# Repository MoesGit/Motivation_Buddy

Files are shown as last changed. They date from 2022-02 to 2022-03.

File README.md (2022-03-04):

# Motivation_Buddy
A little IoT Device for Motivation and personal Messages. </br>
</br>
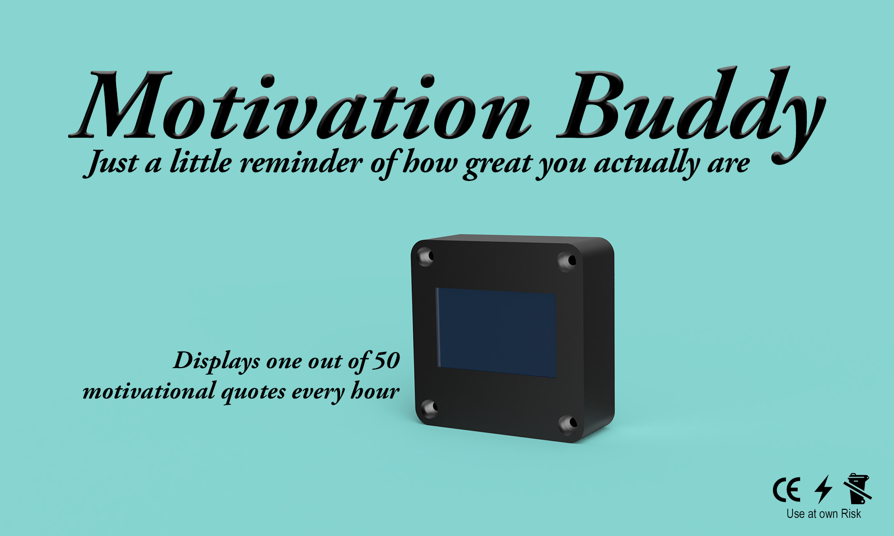
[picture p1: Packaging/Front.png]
Graph1

(just for fun and definitely has no CE certificate and not China Exportet since it is made at home (Please don't sue me. The Logo is just for fun :) ))

## What is it?
The Motivation Buddy is a little device, that can display a Motivation Quoate every hour or so. You can also hook it up to your WIFI to send messages and pre-set images to the screen. I designed this project as a gift. 

If you do not want to hook it up to Wifi it just displays a random quote which changes from time to time (i think - haven't tested it)

## Required Hardware:
- [ESP8266 D1 Mini](https://www.az-delivery.de/it/products/d1-mini-pro)
- [0.96 Inch Oled I2C Display](https://www.az-delivery.de/it/products/0-96zolldisplay?_pos=1&_sid=81bd66783&_ss=r)
- 4x [M2x6](https://www.amazon.de/Schrauben-Edelstahl-Sechskopf-Unterlegscheiben-Aufbewahrung/dp/B085LJYF3G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)
- Brass Inserts 4x [M2x4x3.5](https://www.amazon.de/VIGRUE-Gewindeeinsatz-Einpressmutter-Gewindebuchsen-Kunststoffteiledurch/dp/B08DHYD73Q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) 
- 4x 4cm Wire (2 [Arduino Jumper](https://www.amazon.de/Female-Female-Male-Female-Male-Male-Steckbr%C3%BCcken-Drahtbr%C3%BCcken-bunt/dp/B01EV70C78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) cables cut in halfe work too)

## Additionally: 
- [Arduino IDE](https://www.arduino.cc/en/software) addapted for [ESP8266](https://chewett.co.uk/blog/937/configuring-wemos-d1-mini-pro-esp8266-arduino-ide/)
- Solderin Iron 
- Solder
- 3D Printer 

## How to [Hardware]:

### 1) 3D Printing  
3D print the case and cover from the latest version in [3dModells](./3dModells/). I used the [colorFabb Steelfill PLA Filament](https://colorfabb.com/de/steelfill) for a High-Quality feeling and a bit of extra weight. 

Printer: 
- Ender 3 Pro
    
Print Settings (Cura 4.12.1): 
- Steal Nozzel 0.6mm
- Bed Tmp: 60°
- Nozzle: 215°
- Speed: 50mm/s
- Support: Tree, touching build plate
 - Retraction: 5mm

### 2) Soldering  
Solder the display to the ESP8266 D1 mini as shown below: 

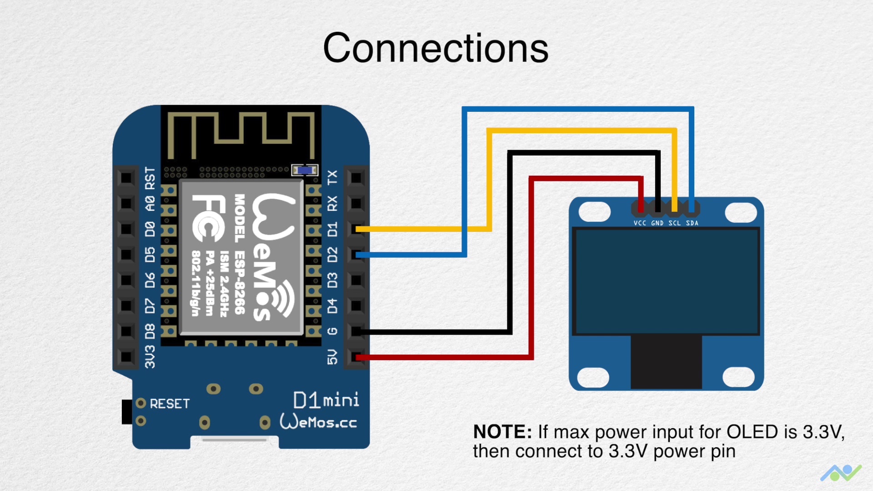
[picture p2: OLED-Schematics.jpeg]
solder_help

image from [electronics-lab.com]( https://www.electronics-lab.com/project/network-clock-using-esp8266-oled-display/)

### 3) Inserts
Use the soldering iron to insert the Brass Inserts into the 4 holes in the base of the case. 

### 4) Asembly 
- Push the Oled display gently (but with a little bit of force) into the cover, so that the 4 pins of the oled align with the cutout in the back and only the display is visible from the front. 
- Put the ESP8622 into the casing and align it with the usb cutout. 
- Choose and orientation of the display-cover (it is a square so you can rotate it) and put it gently on top. Make sure the wires go around the WeMos Processor. 
- Gently screw in the 4 screws in each corner. 
   
## How to [Software]:
1) Create a Google spreadsheet (See the [MotivationBuddy.xlsx](./Software/MotivationBuddy.xlsx) as template)
2) Navigate to Extensions -> "Apps Script" (see image below)
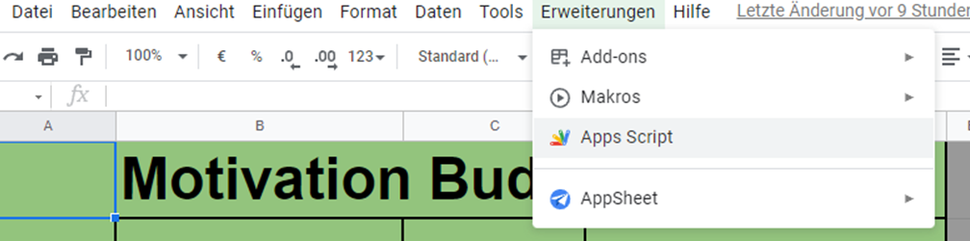
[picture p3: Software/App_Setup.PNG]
app

3) copy the [Google Doc Script](./Software/google_doc_excel_script.txt) into the Apps Script and enter the URL in the first line. 
4) Go to Deploy and then "new deployment"
5) Select Web App and set the authorisation to "everyone" 
6) Copy the generated code to the [settings.h](./Software/Motivation_Buddy_V2/settings.h) file at the variable "GOOGLE_SCRIPT_ID" . 
7) At the  [settings.h](./Software/Motivation_Buddy_V2/settings.h) also enter your Wifi Network settings. 
8) Kompile and Flash your [.ino Script](./Software/Motivation_Buddy_V2/Motivation_Buddy_V2.ino) to your ESP8266

9) (Optional) Change the Bitmaps to a image you like or create new .h-files with new bitmaps (dont forget to change the Switch-Case statement if you do). Images can be converted [here](https://diyusthad.com/image2cpp) (external converter for image to cpp bitmap)
## (Optional) Packaging
1) "Product" Info-Card </br>
If you want to make the gadget look more like a product print out the [Front](./Packaging/Front.png) and [Back](./Packaging/Back.png) of the provided "Info"-Card. 

2) Cardboard Box </br>
Get a Box roughly the size of <19 x 12.5 x 4.5 cm>  

3) Power Supply </br>
Get a power supply and put it in the box

4) Print the inlay </br>
3D Print the [inlay](./Packaging/inlay.stl) 

5) Bubble Wrap </br>
Bubble Wrap the Gadget and put it in the Inlay. 

6) READY! </br>
Send it out to your loved onces or Hustle-Buddies
packaging

## What now?
If you have any suggestions or want to change something please do so but contact me. I am interested how this porject can be used. 

Do you want to sell it? -> Contact me and lets talk about it 

## Sources: 
Circuit Image: https://www.electronics-lab.com/project/network-clock-using-esp8266-oled-display/
</br>
Code Idea and Tutorial: https://www.youtube.com/watch?v=0LoeaewIAdY </br>
Thingiverse Model inspirations: https://www.thingiverse.com/thing:857858

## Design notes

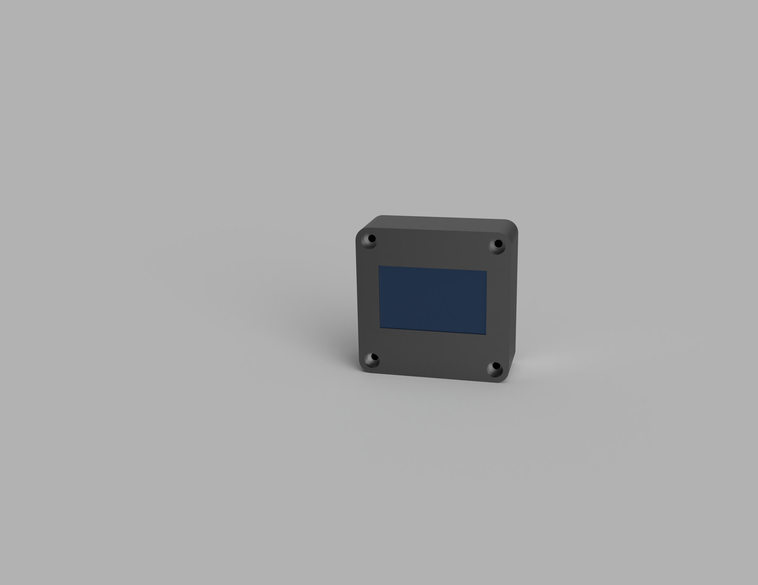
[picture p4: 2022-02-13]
Packaging/render_1.png

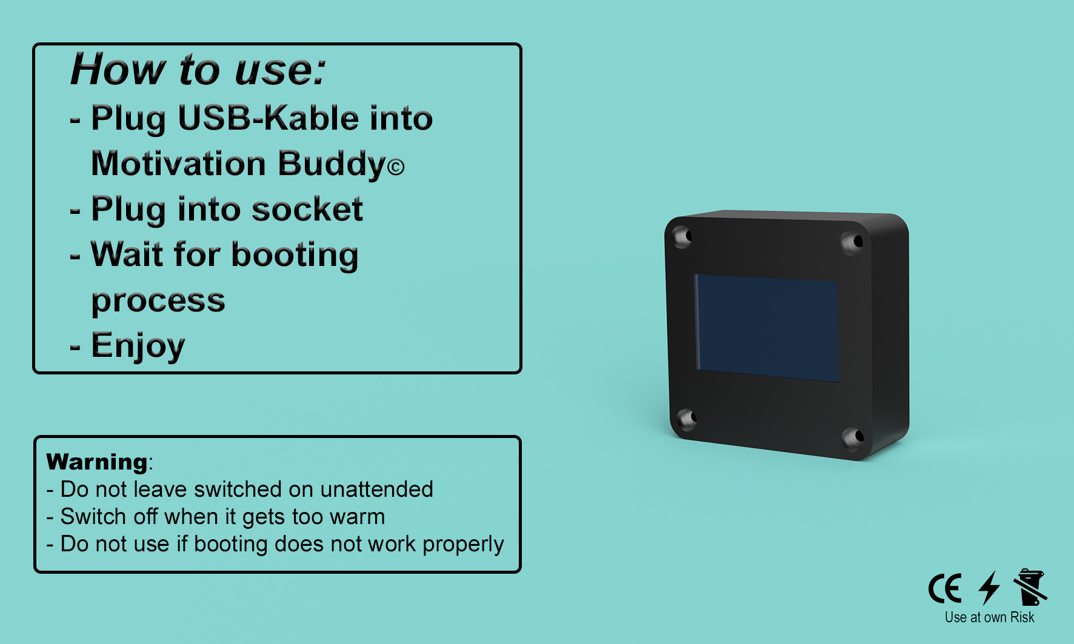
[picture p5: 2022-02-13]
Packaging/Back.png

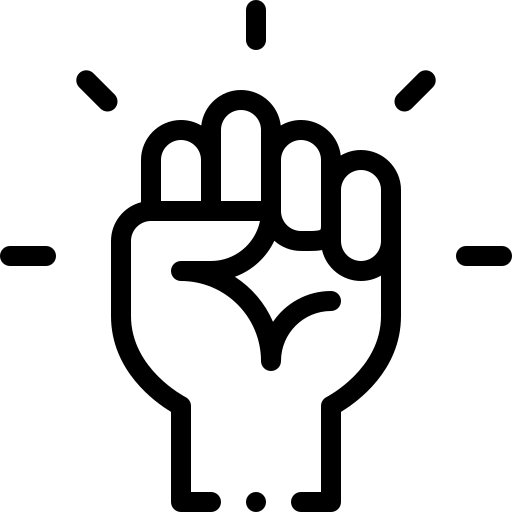
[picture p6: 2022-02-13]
Packaging/fist.png

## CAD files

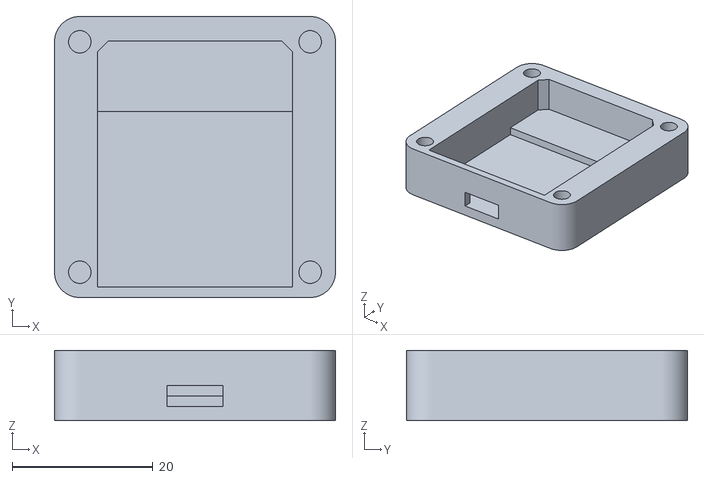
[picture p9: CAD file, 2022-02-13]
3dModells/V5/Huelle.stl
40.0 x 40.0 x 10.0

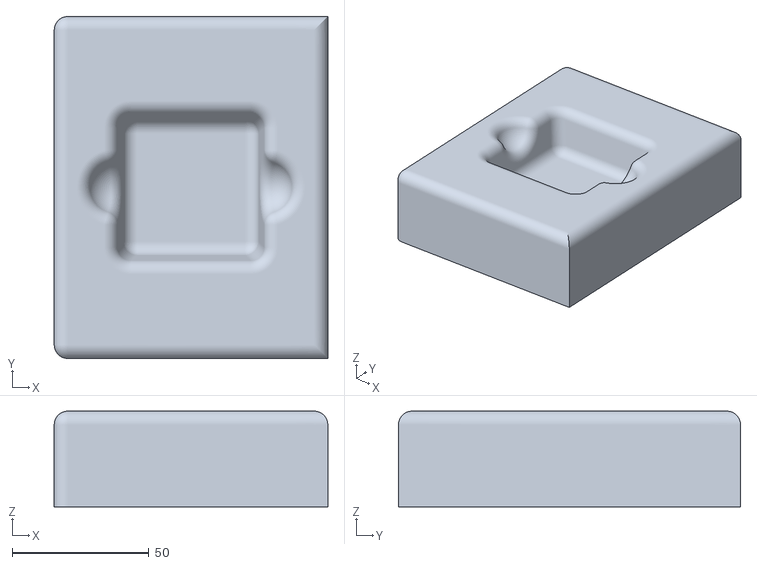
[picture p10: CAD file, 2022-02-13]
Packaging/inlay.stl
100.0 x 125.0 x 35.0

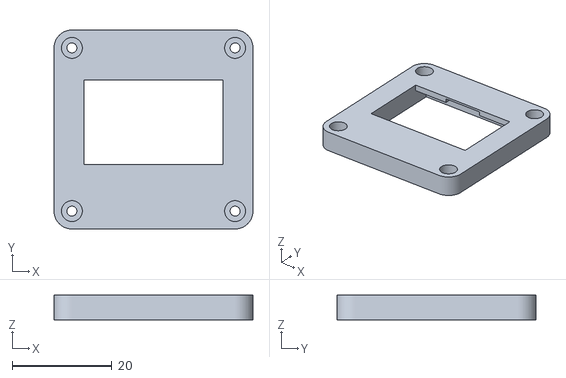
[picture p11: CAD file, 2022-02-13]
3dModells/V5/Cover.stl
40.0 x 40.0 x 5.00

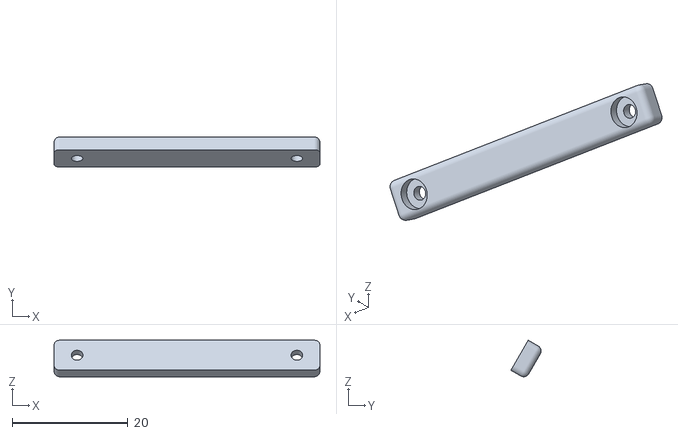
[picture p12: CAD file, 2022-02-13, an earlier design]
3dModells/V1/Clamp.stl
46.0 x 5.23 x 6.33

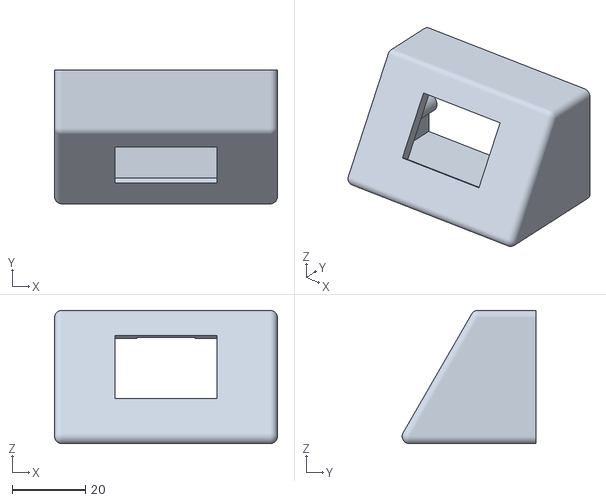
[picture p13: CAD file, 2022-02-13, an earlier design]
3dModells/V3/Körper2.stl
61.0 x 36.6 x 36.4

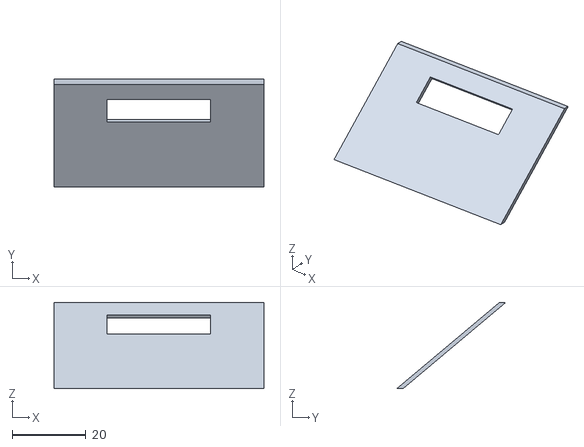
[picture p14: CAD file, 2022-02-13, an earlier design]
3dModells/V4/Lock.stl
56.8 x 29.3 x 23.3

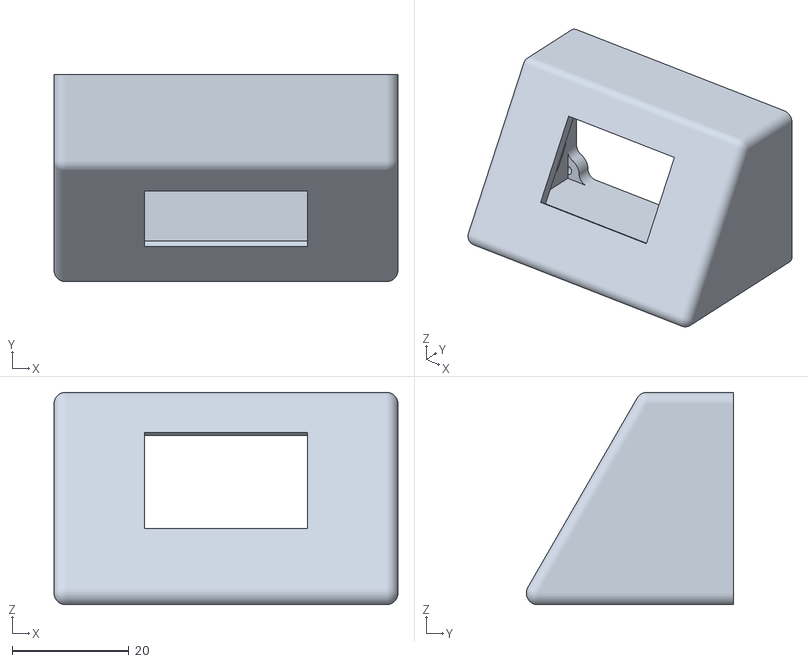
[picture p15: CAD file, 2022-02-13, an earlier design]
3dModells/V1/Housing.stl
59.0 x 35.6 x 36.4

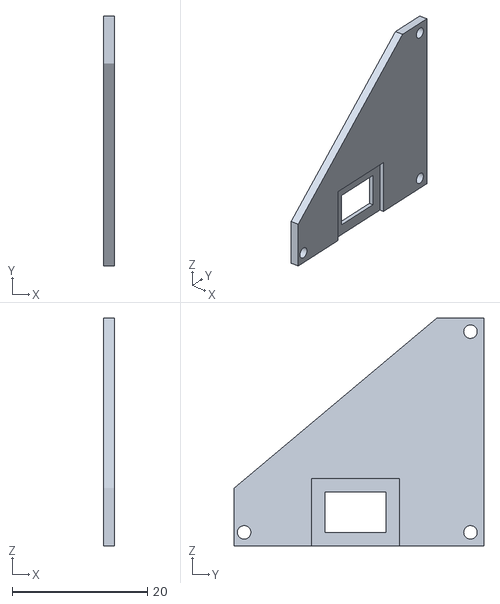
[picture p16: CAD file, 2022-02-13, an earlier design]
3dModells/V4/Cover.stl
1.60 x 37.0 x 33.7

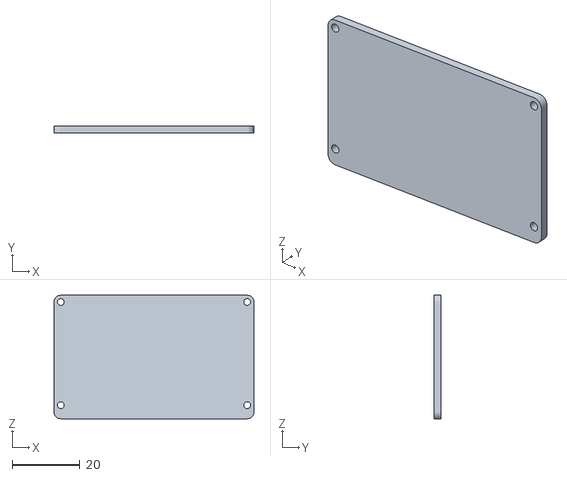
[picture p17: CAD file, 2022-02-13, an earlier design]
3dModells/V1/Backplate.stl
59.0 x 2.00 x 36.4

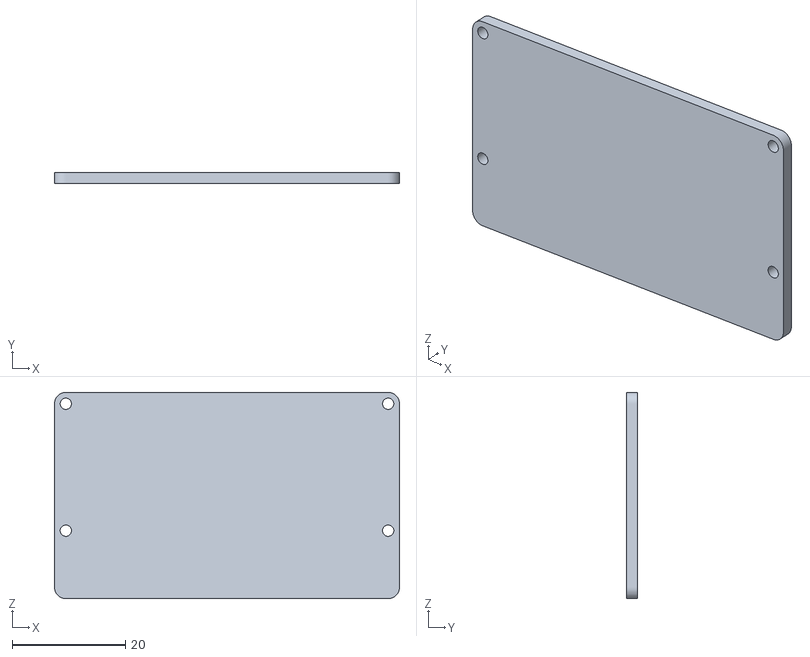
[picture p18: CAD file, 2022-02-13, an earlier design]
3dModells/V2/Backplate.stl
61.0 x 2.00 x 36.4

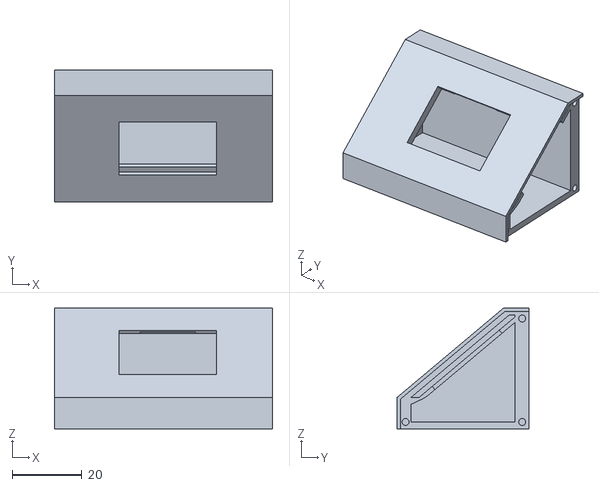
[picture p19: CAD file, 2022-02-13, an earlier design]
3dModells/V4/Base.stl
62.6 x 38.0 x 34.7

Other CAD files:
3dModells/V2/Case.stl

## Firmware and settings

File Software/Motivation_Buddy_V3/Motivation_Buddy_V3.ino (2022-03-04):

/***************************************************************************************/
/*                                                   
                            WELCOME TO THE CODE 
                            
            - is this code perfect?            -> def. not 
            - does it work?                    -> kinda for what i use it for
            - can it be done way more efficent -> YES! 
            - am I to lazy to change it?       -> maybe 
         
            - Feel free to change it and contact me! 
            have fun 
*/          
/***************************************************************************************/




#include <ESP8266WiFi.h>
#include <ESP8266WiFiMulti.h>
#include <ESP8266HTTPClient.h>
#include <WiFiClientSecureBearSSL.h>
#include <Wire.h>
#include <Adafruit_GFX.h>
#include <Adafruit_SSD1306.h>

/********************************************************************************/

//include images and motivation quotes
#include "heart_map.h"
#include "paw_map.h"
#include "igel_map.h"
#include "wahl_map.h"
#include "motivation_quotes.h"
#include "settings.h"

/********************************************************************************/

// Constants to set Time intervalls
const int sendInterval = 500;
const int textdelay = 600000; // ~1h
int txt_counter = 1200;

/********************************************************************************/

// Constants and Defines for display and wifi
// Declaration for an SSD1306 display connected to I2C (SDA, SCL pins)
#define SCREEN_WIDTH 128 // OLED display width, in pixels
#define SCREEN_HEIGHT 64 // OLED display height, in pixels
#define OLED_RESET     -1 // Reset pin # (or -1 if sharing Arduino reset pin)
#define SCREEN_ADDRESS 0x3C ///< See datasheet for Address; 0x3D for 128x64, 0x3C for 128x32
Adafruit_SSD1306 display(SCREEN_WIDTH, SCREEN_HEIGHT, &Wire, OLED_RESET);
ESP8266WiFiMulti WiFiMulti;
std::unique_ptr<BearSSL::WiFiClientSecure>client(new BearSSL::WiFiClientSecure);


void oled_info(int errorcode) {
  // 0 all good
  // 1 error

  if (errorcode == 1) {
    // ERROR
     Serial.println("In ERROR OLED INFO Function " );
    display.setCursor(8, 50); // set cursor to botom
    display.setTextSize(1);
    display.setTextColor(SSD1306_WHITE);        // Draw white text
    display.println("[ *** NO WIFI *** ]");
    display.display();
  }


}

void print_image(int img_id) {
  display.clearDisplay(); //for Clearing the display
  switch (img_id) {
    case 1:
      display.drawBitmap(0, 0, heart_map, 128, 64, WHITE);
      break;
    case 2:
      display.drawBitmap(0, 0, paw_map, 128, 64, WHITE);
      break;
    case 3:
      display.drawBitmap(0, 0, wahl_map, 128, 64, WHITE);
      break;
    case 4:
      display.drawBitmap(0, 0, igel_map, 128, 64, WHITE);
      break;
    default:
      display.drawBitmap(0, 0, igel_map, 128, 64, WHITE);
      break; // Wird nicht benötigt, wenn Statement(s) vorhanden sind
  }


  display.display();
  delay(sendInterval);
}

void testdrawstyles(String str) {
  // Scroll full screen
  display.clearDisplay();
  drawFrames();
  display.setCursor(0, 10);
  display.setTextSize(1);
  display.setTextColor(SSD1306_WHITE);        // Draw white text
  display.println(str.c_str());
  display.display();

}

void drawFrames() {
  display.drawLine(0, 0, display.width() - 1, 0, WHITE);
  display.drawLine(0, display.height() - 1, display.width() - 1, display.height() - 1, WHITE);

}

void print_quote(){
    int rand_number = random(51);
    Serial.println(quote[rand_number]);
    testdrawstyles(quote[rand_number]);
}




void setup() {
  Serial.begin(115200);
  delay(10);

  // SSD1306_SWITCHCAPVCC = generate display voltage from 3.3V internally
  if (!display.begin(SSD1306_SWITCHCAPVCC, SCREEN_ADDRESS)) { // Address 0x3D for 128x64
    Serial.println(F("SSD1306 allocation failed"));
    for (;;); // Don't proceed, loop forever
  }


  WiFi.mode(WIFI_STA);
  //WiFi.begin(ssid, password);
  WiFiMulti.addAP(ssid, password);

  Serial.println("Started");
  Serial.print("Connecting");
  //while (WiFi.status() != WL_CONNECTED) {
  //  delay(500);
  // Serial.print(".");
  //}

  Serial.println("Ready to go");

  //testdrawstyles();
}

void loop() {

  if ((WiFiMulti.run() == WL_CONNECTED)) { //does not work? 
    update_display();
    delay(sendInterval);
  } else { //TODO Fix error msg
    display.clearDisplay();
    display.println("No Internet Connection");
  }

}

void update_display(void) {
  HTTPClient http;
  client->setInsecure();
  String url = "https://script.google.com/macros/s/" + GOOGLE_SCRIPT_ID + "/exec?read";
  Serial.print("Making a request ");
  Serial.println(url.c_str());
  http.begin(*client, url.c_str()); //Specify the URL and certificate
  http.setFollowRedirects(HTTPC_STRICT_FOLLOW_REDIRECTS);
  int httpCode = http.GET();
  String payload;
  Serial.println(httpCode);
  if (httpCode > 0 ) { //Check for the returning code 
    payload = http.getString();

    if (payload.length() > 200){ // Error in payload 
          Serial.println("Error in Payload");
          Serial.println("Automation mode");
          if (txt_counter < 1200) { //BUFFER
            txt_counter = txt_counter + 1;
          } else {
            print_quote();
            oled_info(1);
            txt_counter = 0;
          }
       
    }else{ //everything is fine DO CODE
 
      // Displaying the different things 
      if (payload.length() < 2) { //Print image
        if (payload.toInt() == 0) { //get random motivation quote
          if (txt_counter < 1200) {
            txt_counter = txt_counter + 1;
          } else {
            print_quote();
            txt_counter = 0;
          }
        } else { //Print image
          print_image(payload.toInt());
          txt_counter = 1200;
        }
      } else { //Print Text
        Serial.print("Http Code: ");
        Serial.println(httpCode);
        Serial.println(payload);
        testdrawstyles(payload);
        txt_counter = 1200;
      }
      Serial.print("Text Count: ");
      Serial.print(txt_counter);
      Serial.println(" | Quote changes at 1200");

    }

    
  } else { // No internet connection or error in request 
    Serial.println("Error on HTTP request");
    Serial.println("Automation mode");
    if (txt_counter < 1200) { //BUFFER
      txt_counter = txt_counter + 1;
    } else {
      print_quote();
      oled_info(1);
      txt_counter = 0;
    }
  }
  http.end();
}

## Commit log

2022-02-13 Inital file commit
    [Backplate.stl, Base.stl, Braket.stl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]
2022-02-13 Added more docu
    [MotivationBuddy.xlsx]
